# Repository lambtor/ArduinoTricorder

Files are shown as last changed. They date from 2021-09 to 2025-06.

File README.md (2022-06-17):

# ArduinoTricorder
WIP: list of digital assets that could be used with arduino tricorder 

<ul>
<li><strong>Home Screen: </strong>          showing a very simplified equivalent of windows BGInfo</li>
<li><strong>RGB Color Scanner: </strong>    OK</li>
<li><strong>Climate Scanner:</strong>		   OK - updates bar graphs to reflect data without requiring internal loops</li>
<li><strong>Left-side LED: </strong>        OK, stacks on color scanner mode</li>
<li><strong>Power LED:</strong>             Functional, will either cycle colors or show color based on battery power %</li>
<li><strong>Button Support:</strong>        OK - using easybutton library pulled from elsewhere on github (see bottom of this readme)</li>
<li><strong>Microphone Spectrum <br/>
Visualization:</strong>         OK - not the most accurate thing, but has a very high refresh rate.  Uses AdafruitZero_FFT library for FFT calculations.</li>
<li><strong>Thermal camera:</strong>       OK</li>
<li><strong>Sound playback <br/>
via trigger on <br/>
separate board:</strong>       OK</li>
<li><strong>Magnetometer for <br/>
door close to sleep:</strong>  OK</li>
<li><strong>ID LED (8) color <br/>
change via <br/>
potentiometer:</strong>  OK</li> 
	<li><strong>Neopixels above buttons:</strong>	OK - set #define NEOPIXEL_LED_COUNT 3 if you only have PWR / EMRG / ID wired up </li>
	<li><strong>Tom Servo Mode:</strong> 	OK - repeating "canned" animation</li>
  </ul>
<br/>
Draw operations on the display from the arduino typically aren't that fast.  The FFT draw code calculates a list of bar heights, then uses fillRect() to create the bars.  At the end of the bar drawing operations, these bar heights are stored in a "previous" bar height array.  From that point on, each bar draw operation calculates the difference between "new" bar heights and "previous".  If "new" is larger than "previous", it only draws enough to extend the "previous" height to the "new" one.  If "new" is less than "previous", it draws black lines to shorten the "previous" height down to the "new" one.  This relative display update method removes the use of a full screen blank operation, and minimizes flickering.<br/>
<br/>
<br/>
All 3d models for shell are available on <a href="https://www.printables.com/model/128500-star-trek-next-generation-tricorder-tr-580-v1-ardu">printables</a> or <a href="https://www.thingiverse.com/thing:5199642">thingiverse</a>. Printables has latest version with USB-C breakout plug at top of body "hat".
<br/>
Refrences used:<br/>
<a href="https://github.com/adafruit/Adafruit_nRF52_Arduino/blob/master/variants/feather_nrf52840_sense/variant.h">Adafruit board pinout map</a><br/>
<a href="https://github.com/evert-arias/EasyButton">Easybutton arduino library</a><br/><br/>

decibel demo gif

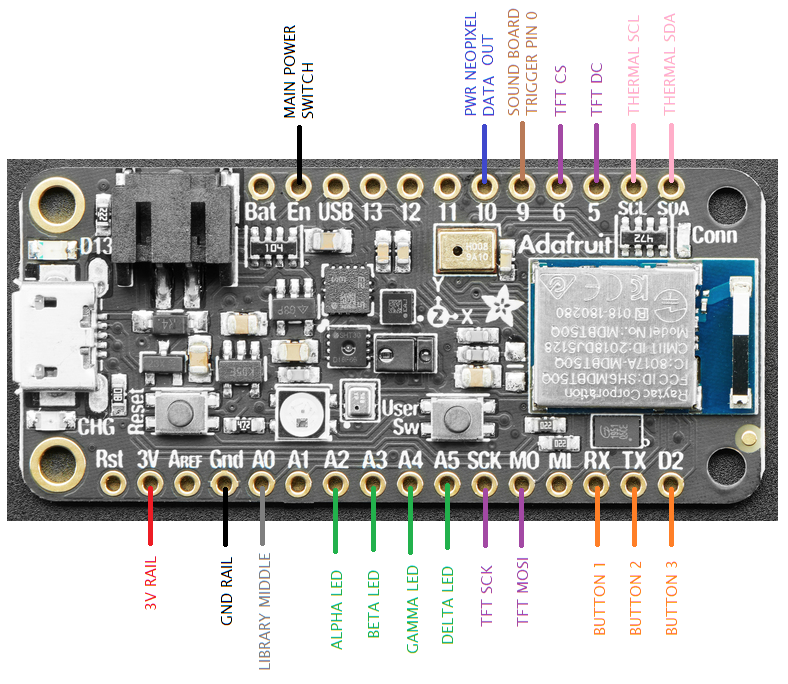
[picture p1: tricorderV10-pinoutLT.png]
board pinout


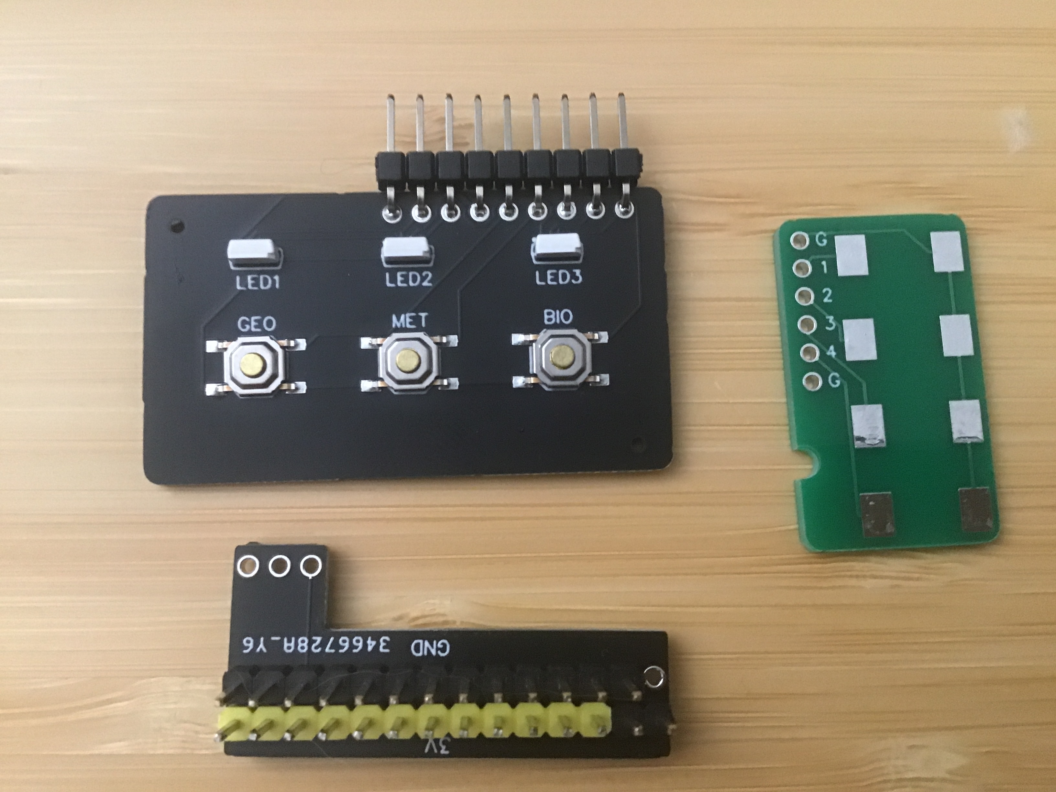
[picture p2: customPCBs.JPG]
PCB Headers


Reference of all parts used in build demoed on youtube:<br/>

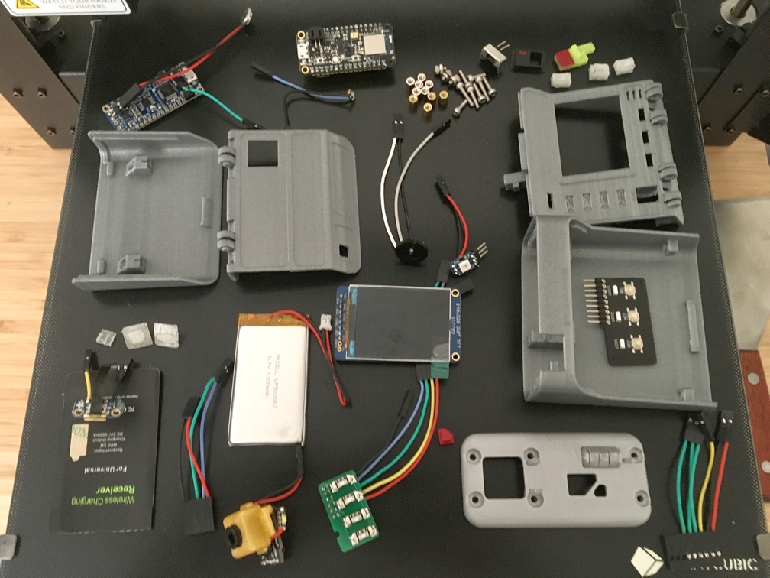
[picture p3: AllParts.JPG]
all_parts


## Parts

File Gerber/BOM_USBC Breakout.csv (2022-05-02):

ID | Name | Designator | Footprint | Quantity | Manufacturer Part | Manufacturer | Supplier | Supplier Part | Price
1 | USB-C-SMD_A4Q1605-A-03-R | U3 | USB-C-SMD_A4Q1605-A-03-R | 1 | A4Q1605-A-03-R | TECONN | LCSC | C694913 | 0.342

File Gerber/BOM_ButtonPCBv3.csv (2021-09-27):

ID | Name | Designator | Footprint | Quantity | Manufacturer Part | Manufacturer | Supplier | Supplier Part | Price
1 | LED-SMD_WS2812B-4020 | LED1,LED2,LED3 | LED-SMD_WS2812B-4020 | 3 | WS2812B-4020 | Worldsemi | LCSC | C965557 | 0.116
2 | SW-SMD_4P-L5.1-W5.1-P3.70-LS6.5-TL-2 | BIO,MET,GEO | SW-SMD_4P-L5.1-W5.1-P3.70-LS6.5-TL-2 | 3 | TS-1187A-C-C-B | XKB Enterprise | LCSC | C318889 | 0.024

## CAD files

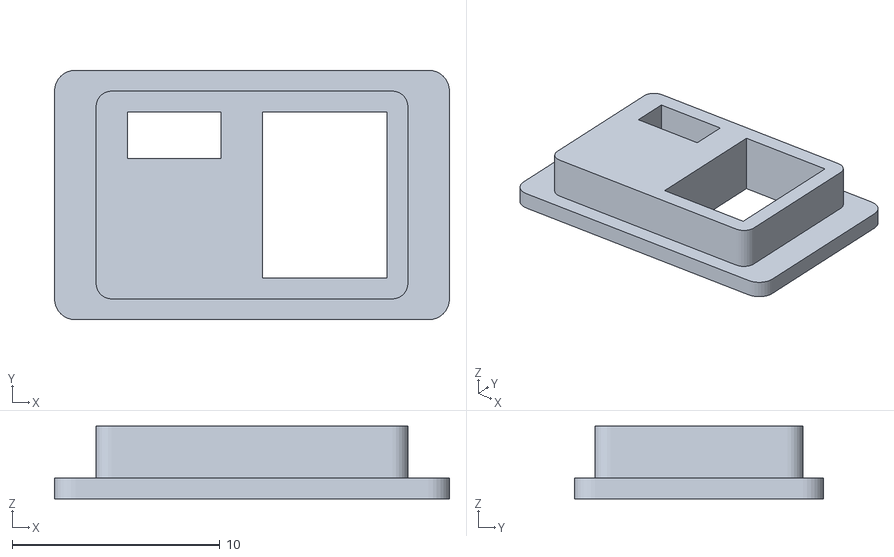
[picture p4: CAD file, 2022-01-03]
ShellModels/pwrSwitch-frame.stl
19.0 x 12.0 x 3.50

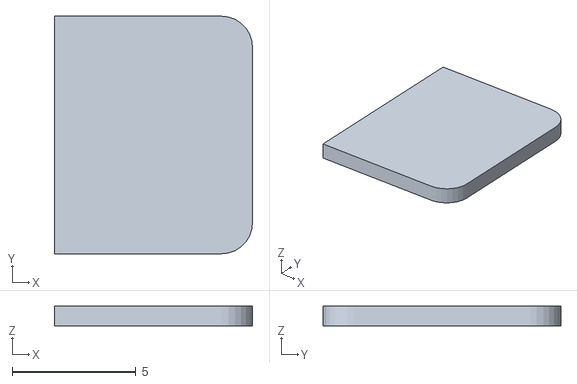
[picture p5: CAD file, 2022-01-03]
ShellModels/pwrSwitch-redSwatch.stl
8.00 x 9.60 x 0.8

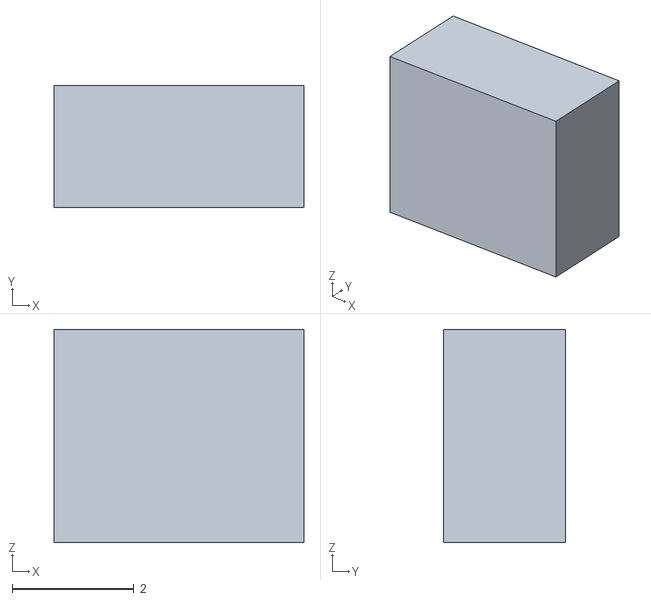
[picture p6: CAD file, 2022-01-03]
ShellModels/pwrSwitch-glass.stl
4.10 x 2.00 x 3.50

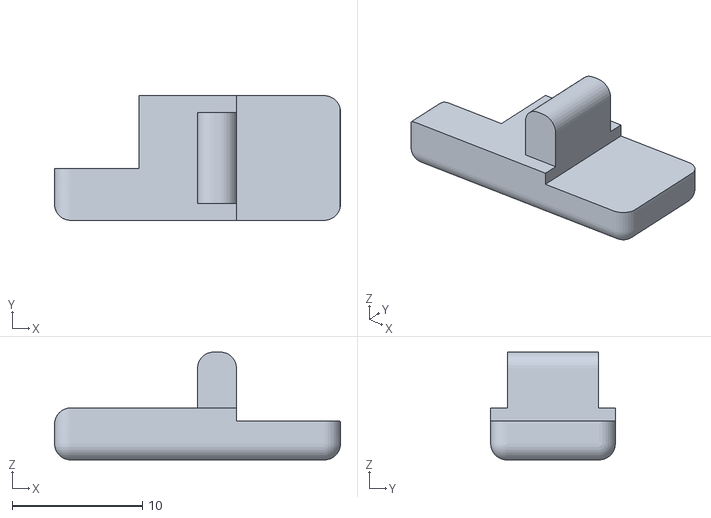
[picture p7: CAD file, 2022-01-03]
ShellModels/pwrSwitch.stl
22.0 x 9.60 x 8.30

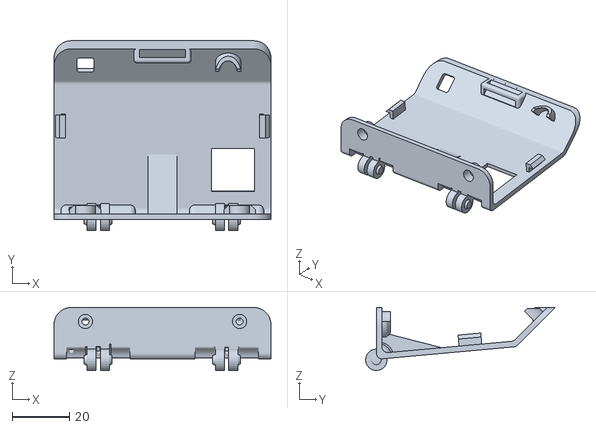
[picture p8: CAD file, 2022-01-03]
ShellModels/door-shellTop.stl
76.0 x 66.4 x 22.1

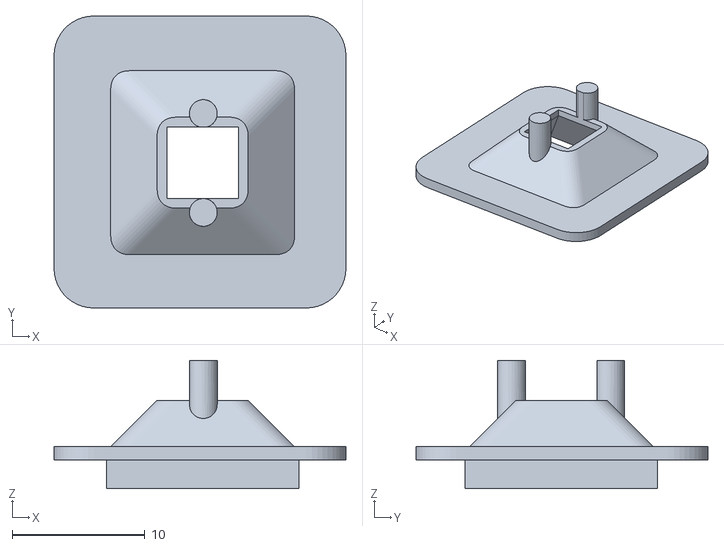
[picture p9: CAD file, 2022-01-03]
ShellModels/door-EMRGframe.stl
22.0 x 22.0 x 9.65

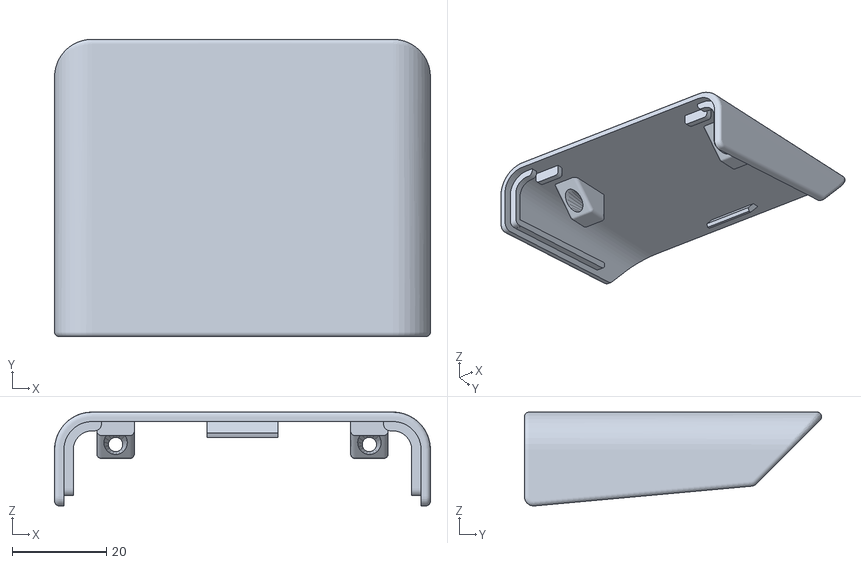
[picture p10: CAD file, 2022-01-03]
ShellModels/door-shell.stl
80.0 x 63.3 x 20.0

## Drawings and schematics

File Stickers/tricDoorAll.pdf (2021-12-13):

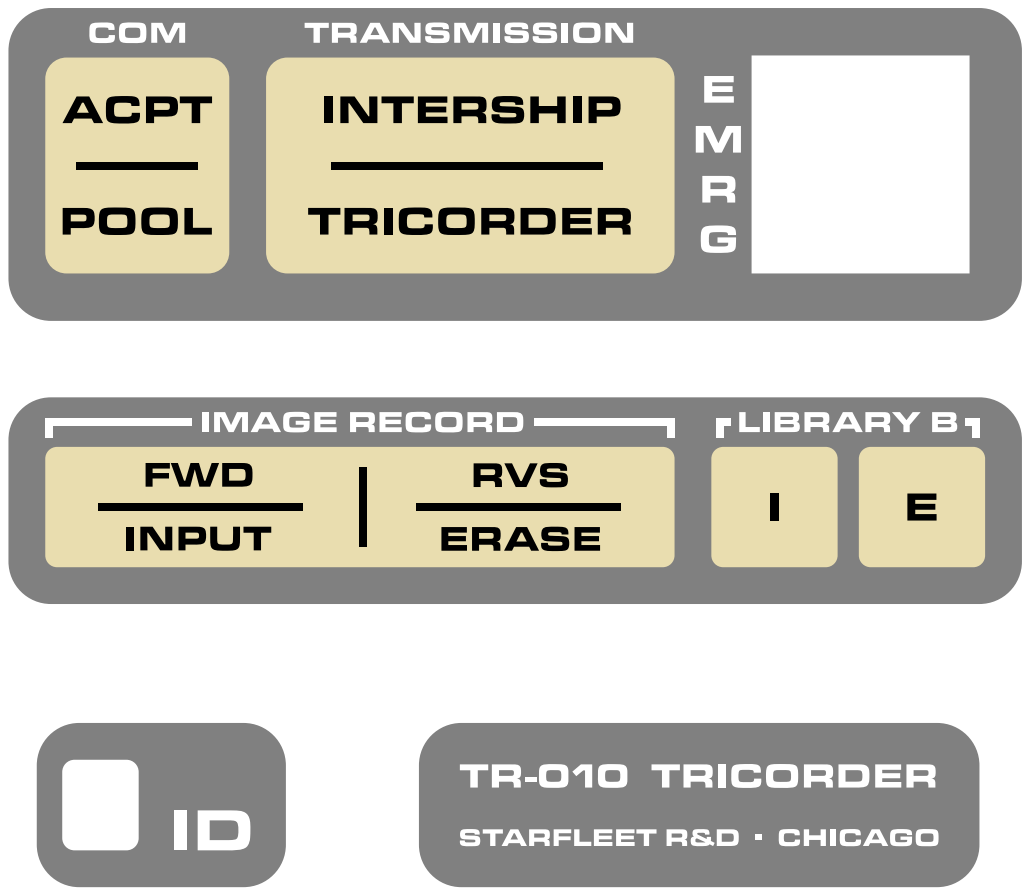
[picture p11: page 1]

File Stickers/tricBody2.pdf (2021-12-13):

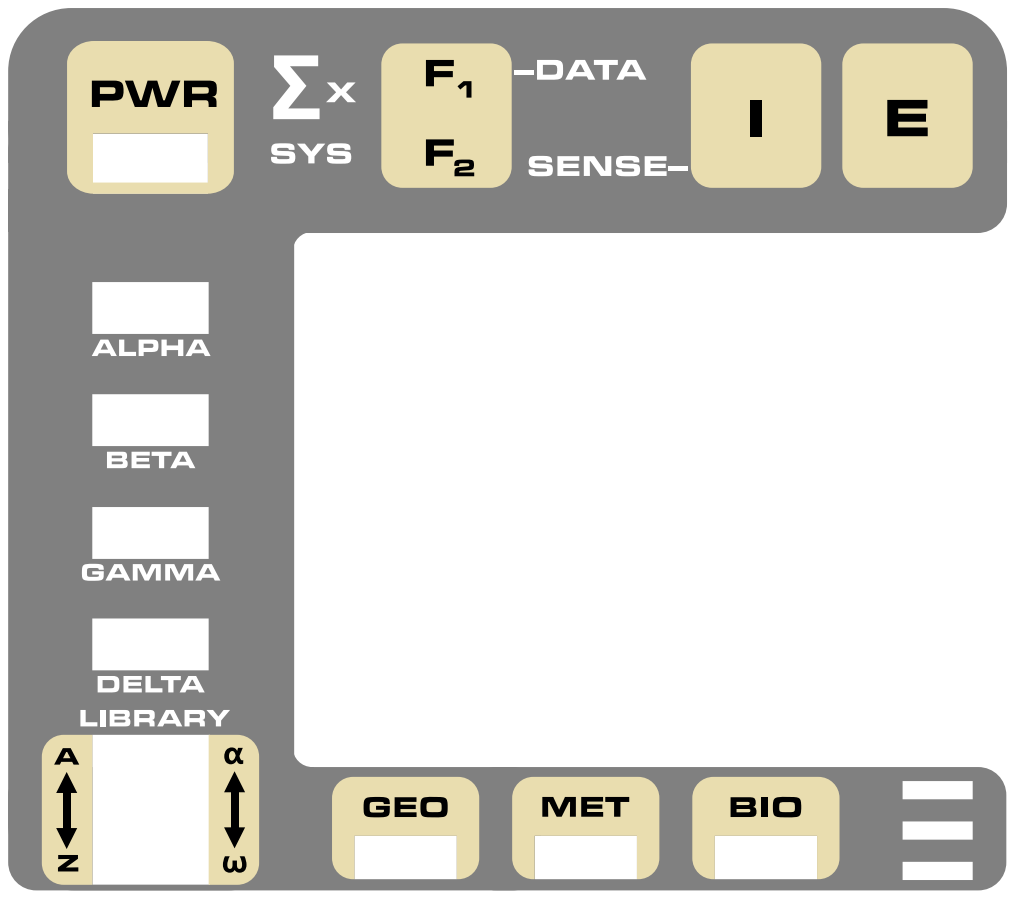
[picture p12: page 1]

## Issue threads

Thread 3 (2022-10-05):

Missing STL files

GrimWreeper, 2022-10-05:
Hi lambtor,
Firstly, great job on the build, you should be very proud.

Just wonderining if you have more STL files laying around that might have been missed in the commit? As it stands you can only print about 1/3 of a tricorder.

Best of luck to ya

GrimWreeper, 2022-10-05:
https://www.printables.com/model/128500-star-trek-next-generation-tricorder-tr-580-v1-ardu/files

found them. Ignore more. I need to RTFM.

Closed 2022-10-05.

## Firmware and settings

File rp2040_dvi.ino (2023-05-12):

// Basic full-color PicoDVI test. Provides a 16-bit color video framebuffer to
// which Adafruit_GFX calls can be made. It's based on the EYESPI_Test.ino sketch.
#include <PicoDVI.h>                  // Core display & graphics library
#include <Fonts/FreeSansBold18pt7b.h> // A custom font
#include <Fonts/lcars15pt7b.h>
#include <Fonts/lcars11pt7b.h>
#include <EasyButton.h>
#include <Adafruit_NeoPixel.h>

// Here's how a 320x240 16-bit color framebuffer is declared. Double-buffering
// is not an option in 16-bit color mode, just not enough RAM; all drawing
// operations are shown as they occur. Second argument is a hardware
// configuration -- examples are written for Adafruit Feather RP2040 DVI, but
// that's easily switched out for boards like the Pimoroni Pico DV (use
// 'pimoroni_demo_hdmi_cfg') or Pico DVI Sock ('pico_sock_cfg').
DVIGFX16 tft(DVI_RES_320x240p60, adafruit_feather_dvi_cfg);

//pin 9 is free, as pin_a6 is for vbat and is otherwise known as digital 20
#define VOLT_PIN 					D7		//INPUT_POWER_PIN
#define SOUND_TRIGGER_PIN			D9

//buttons, scroller	- d2 pin supposed to be pin #2
//button on the board is connected to pin 7.  TX is pin 0, RX is pin 1 - these are normally used for serial communication

#define BUTTON_1_PIN				PIN_SERIAL1_RX
#define BUTTON_2_PIN				PIN_SERIAL1_TX
//adafruit defines physically labeled pin D2 as pin 2 in its header file, but it does not respond when set as an input by default.
//you will need to modify system_nrf52840.c file by adding
//#define CONFIG_NFCT_PINS_AS_GPIOS (1)
//YOU WILL SEE THIS CONSTANT REFERENCED IN THAT FILE, with compiler-conditional logic around it to actually free up the NFC pins, but only if that constant exists in that file
#define BUTTON_3_PIN				D12

//pin 7 is the board button
#define BUTTON_BOARD				PIN_BUTTON
//only need 1 pin for potentiometer / scroller input. both poles need to be wired to GND and 3v - order doesn't matter
#define PIN_SCROLL_INPUT			D25

#define SCAN_LED_PIN_1 			A0
#define SCAN_LED_PIN_2 			A1
#define SCAN_LED_PIN_3 			A2
#define SCAN_LED_PIN_4 			A3
#define LED_RED             PIN_LED
#define SCAN_LED_BRIGHTNESS 	(32)

//neopixel power LED. must use an unreserved pin for this.  PWR, ID, EMRG all use this pin
#define NEOPIXEL_CHAIN_DATAPIN		(10)
#define NEOPIXEL_BRIGHTNESS 		(64)
#define NEOPIXEL_LED_COUNT 			(6)
// built-in pins: D4 = blue conn LED, 8 = neopixel on board, D13 = red LED next to micro usb port
// commented out lines are pre-defined by the adafruit board firmware
#define NEOPIXEL_BOARD_LED_PIN		(8)
//system os version #. max 3 digits
#define DEVICE_VERSION			"0.94"
//theme definition: 0 = TNG, 1 = DS9, 2 = VOY
#define UX_THEME	(0)
#define ST77XX_BLACK 0x0000
#define ST77XX_RED 0xF800
#define ST77XX_WHITE 0xFFFF

#if UX_THEME == 0
	// TNG colors here
	#define color_SWOOP				0xF7B3
	#define color_MAINTEXT			0x9E7F
	//#define color_MAINTEXT			0xC69F
	#define color_LABELTEXT			0x841E
	#define color_HEADER			0xFEC8
	#define color_TITLETEXT			0xFEC8
	//196,187,145
	#define color_LABELTEXT2		0xC5D2
	//204,174,220
	#define color_LABELTEXT3		0xCD7B
	#define color_LABELTEXT4		0xEE31
	#define color_LEGEND			0x6A62
	//210,202,157
	#define color_FFT				0xDEB5
#elif UX_THEME == 1
	// ds9
	#define color_SWOOP			0xD4F0
	#define color_MAINTEXT		0xBD19
	#define color_LABELTEXT		0x7A8D
	#define color_HEADER		0xECA7
	#define color_TITLETEXT		0xC3ED
	//to-do: find fitting options for these to mesh with ds9
	#define color_LABELTEXT2	0xC5D2	
	#define color_LABELTEXT3		0xCD7B	
	#define color_LABELTEXT4		0xEE31
	#define color_LEGEND			0x6A62
	#define color_FFT				0xDEB5
#elif UX_THEME == 2
	// voy
	#define color_MAINTEXT		0x9E7F
	#define color_SWOOP			0x7C34
	#define color_LABELTEXT		0x9CDF
	#define color_HEADER		0xCB33
	#define color_TITLETEXT		0xFFAF
	//to-do: find fitting options for these to mesh with voy
	#define color_LABELTEXT2	0xC5D2
	#define color_LABELTEXT3		0xCD7B
	#define color_LABELTEXT4		0xEE31
	#define color_LEGEND			0x6A62
	#define color_FFT				0xDEB5
#endif

#define color_REDLABELTEXT		0xE000
#define color_REDDARKLABELTEXT	0x9800
#define color_REDDATATEXT		0xDEFB

//use labeltext3 for servo ltpurple
#define color_SERVOPINK			0xFE18
#define color_SERVOPURPLE		0x83B7
#define RGBto565(r,g,b) ((((r) & 0xF8) << 8) | (((g) & 0xFC) << 3) | ((b) >> 3))
Adafruit_NeoPixel ledBoard(1, NEOPIXEL_BOARD_LED_PIN, NEO_GRB + NEO_KHZ800);

//power & board color enumerator: blue = 4, green = 3, yellow = 2, orange = 1, red = 0
int mnPowerColor = 4;
bool mbCyclePowerColor = false;
bool mbCycleBoardColor = false;
int mnBoardColor = 4;
//power interval doesn't need to check more than every 30 seconds
int mnPowerLEDInterval = 30000;
int mnIDLEDInterval = 1000;
unsigned long mnLastUpdateIDLED = 0;
int mnCurrentProfileRed = 0;
int mnCurrentProfileGreen = 0;
int mnCurrentProfileBlue = 0;
String msCurrentProfileName = "";
int mnEMRGLEDInterval = 110;
int mnEMRGMinStrength = 8;
int mnEMRGMaxStrength = 212;
int mnEMRGCurrentStrength = 8;
bool mbLEDIDSet = false;
unsigned long mnLastUpdatePower = 0;
unsigned long mnLastUpdateEMRG = 0;
bool mbEMRGdirection = false;
int mnBoardLEDInterval = 5000;
unsigned long mnLastUpdateBoard = 0;

//left scanner leds
int mnLeftLEDInterval = 200;
int mnLeftLEDCurrent = 0;
unsigned long mnLastUpdateLeftLED = 0;

int mnBoardRedLEDInterval = 350;
int mnBoardBlueLEDInterval = 250;
unsigned long mnLastUpdateBoardRedLED = 0;
unsigned long mnLastUpdateBoardBlueLED = 0;
bool mbBoardRedLED = false;
bool mbBoardBlueLED = false;
//button functionality
bool mbButton1Flag = false;
bool mbButton2Flag = false;
bool mbButton3Flag = false;
bool mbButton7Flag = false;
EasyButton oButton1(BUTTON_1_PIN);
EasyButton oButton2(BUTTON_2_PIN);
EasyButton oButton3(BUTTON_3_PIN);
//board button digital pin 7 - use for thermal camera toggle
EasyButton oButton7(BUTTON_BOARD);

bool mbSleepMode = false;
bool mbTomServoActive = false;
unsigned long mnButton2Press = 0;
unsigned long mnButton3Press = 0;
int mnServoButtonWindow = 1500;
//graphs should take 3 seconds for full draw cycle-> 3000 / 80 lines
uint8_t mnServoDrawInterval = 38;
unsigned long mnServoLastDraw = 0;
uint8_t mnCurrentServoGraphPoint = 0;

bool mbHomeActive = false;
unsigned long mnLastUpdateHome = 0;
int mnHomeUpdateInterval = 1000;
bool mbColorInitialized = false;
bool mbRGBActive = false;
int mnRGBScanInterval = 5000;
int mnRGBCooldown = 0;
unsigned long mnLastRGBScan = 0;
bool mbTempInitialized = false;
bool mbHumidityInitialized = false;
bool mbTempActive = false;
bool mbThermalCameraStarted = false;
bool mbThermalActive = false;
bool mbHumidBarComplete = false;
bool mbTempBarComplete = false;
bool mbBaromBarComplete = false;
bool mbMicrophoneStarted = false;
bool mbMicrophoneActive = false;
bool mbMicrophoneRedraw = false;
int mnClimateCooldown = 0;
int mnTempTargetBar = 0;
int mnTempCurrentBar = 0;
int mnHumidTargetBar = 0;
int mnHumidCurrentBar = 0;
int mnBaromTargetBar = 0;
int mnBaromCurrentBar = 0;

//establish graph values
const uint8_t mnarrServoGraphData[] = {3,7,10,12,13,14,14,14,13,12,10,7,4,4,6,8,11,13,14,15,15,15,15,14,13,
									12,10,8,7,6,4,3,2,2,2,3,4,6,8,9,11,12,12,12,11,10,9,7,5,3,3,3,5,7,10,
									11,11,12,12,12,11,11,10,9,9,9,8,8,8,8,7,6,5,5,5,5,4,3,2,2,2};
									

void setup() {
	//NRF_UICR->NFCPINS = 0;
	ledBoard.begin();
	
	//dvi uses begin as initialization
	tft.begin();
	//tft.setRotation(1);
	tft.setFont(&lcars11pt7b);
	tft.setTextSize(1);
	//these goggles, they do nothing!
	tft.setTextWrap(false);
		
	ledBoard.clear();
	ledBoard.setBrightness(NEOPIXEL_BRIGHTNESS);
	
	//set pinmode output for scanner leds
	pinMode(SCAN_LED_PIN_1, OUTPUT);
	pinMode(SCAN_LED_PIN_2, OUTPUT);
	pinMode(SCAN_LED_PIN_3, OUTPUT);
	pinMode(SCAN_LED_PIN_4, OUTPUT);
	
	//set output for board non-neopixel LEDs
	pinMode(LED_RED, OUTPUT);
	
	pinMode(SOUND_TRIGGER_PIN, OUTPUT);
	digitalWrite(SOUND_TRIGGER_PIN, HIGH);
		
	//or it'll be read as low and boot the tricorder into environment section
	pinMode(BUTTON_1_PIN, OUTPUT);
	pinMode(BUTTON_2_PIN, OUTPUT);
	pinMode(BUTTON_3_PIN, OUTPUT);
	pinMode(BUTTON_BOARD, OUTPUT);
	digitalWrite(BUTTON_1_PIN, HIGH);
	digitalWrite(BUTTON_2_PIN, HIGH);
	digitalWrite(BUTTON_3_PIN, HIGH);
	digitalWrite(BUTTON_BOARD, HIGH);	
	delay(10);
		
	//pinMode(PIN_SCROLL_INPUT, INPUT);
	
	pinMode(BUTTON_1_PIN, INPUT);
	pinMode(BUTTON_2_PIN, INPUT);
	pinMode(BUTTON_3_PIN, INPUT);
	
	//pinMode(VOLT_PIN, INPUT);	
	pinMode(BUTTON_BOARD, INPUT);	
	
	/*oButton2.begin();
	oButton2.onPressed(ToggleRGBSensor);	
	
	oButton1.begin();
	oButton1.onPressed(ToggleClimateSensor);
	
	oButton3.begin();
	oButton3.onPressed(ToggleMicrophone);*/
	
	oButton7.begin();
	oButton7.onPressed(ToggleTomServo);
	
	GoHome();
}

void loop() {
	//toggle climate
	oButton1.read();
	//this toggles RGB scanner
	oButton2.read();	
	//toggle microphone
	oButton3.read();
	//toggle thermal camera
	oButton7.read();
			
	RunNeoPixelColor(NEOPIXEL_BOARD_LED_PIN);
	//RunLeftScanner();
	RunHome();
	//blink board LEDs
	RunBoardLEDs();	
	RunTomServo();
}

void GoHome() {
	//if flag set for thermal debug mode, hijack home screen?	
	//reset any previous sensor statuses
	mnRGBCooldown = 0;
	mnClimateCooldown = 0;
	mbHomeActive = true;
	mbRGBActive = false;
	mbTempActive = false;
	mnCurrentServoGraphPoint = 0;
	mnServoLastDraw = 0;
	//SetActiveNeoPixelButton(0);
	
	mbButton1Flag = false;
	mbButton2Flag = false;
	mbButton3Flag = false;
	
	//reset any bar graph values from climate
	mnTempTargetBar = 0;
	mnTempCurrentBar = 0;
	mnHumidTargetBar = 0;
	mnHumidCurrentBar = 0;
	mnBaromTargetBar = 0;
	mnBaromCurrentBar = 0;
	mbHumidBarComplete = false;
	mbTempBarComplete = false;
	mbBaromBarComplete = false;
	mbThermalActive = false;
	mbTomServoActive = false;

	//tft.setFont(&lcars11pt7b);
	tft.setFont(&lcars15pt7b);

	// large block of text
	tft.fillScreen(ST77XX_BLACK);
	// home screen header is 2 rounded rectangles, lines to cut them, 1 black rect as backing for header text
	//fillRoundRect(x,y,width,height,cornerRadius, color)
	//top and bottom borders
	tft.fillRoundRect(26, 1, 289, 22, 11, color_SWOOP);
	tft.fillRoundRect(26, 216, 289, 22, 11, color_SWOOP);
	//left side
	tft.fillRoundRect(1, 1, 68, 66, 32, color_SWOOP);
	tft.fillRoundRect(1, 171, 68, 66, 32, color_SWOOP);
	tft.fillRoundRect(59, 23, 24, 193, 11, ST77XX_BLACK);
	//middle section - needs to be split for profile name and color
	//tft.fillRect(1, 39, 58, 164, color_HEADER);
	//dull all LED colors by 50% to lcarsify them
	tft.fillRect(1, 39, 58, 76, RGBto565((int)min(mnCurrentProfileRed*1.75, 255), (int)min(mnCurrentProfileGreen*1.75, 255), (int)min(mnCurrentProfileBlue*1.75, 255)));
	tft.fillRect(1, 147, 58, 55, RGBto565((int)min(mnCurrentProfileRed*1.75, 255), (int)min(mnCurrentProfileGreen*1.75, 255), (int)min(mnCurrentProfileBlue*1.75, 255)));
	//profile label always shows bkg as swoop color 
	tft.fillRect(1, 119, 58, 24, color_SWOOP);
	
	//middle section black lines
	tft.drawFastHLine(1, 35, 58, ST77XX_BLACK);
	tft.drawFastHLine(1, 36, 58, ST77XX_BLACK);
	tft.drawFastHLine(1, 37, 58, ST77XX_BLACK);
	tft.drawFastHLine(1, 38, 58, ST77XX_BLACK);
	tft.drawFastHLine(1, 39, 58, ST77XX_BLACK);	
	tft.drawFastHLine(1, 40, 58, ST77XX_BLACK);	
	tft.drawFastHLine(1, 201, 58, ST77XX_BLACK);
	tft.drawFastHLine(1, 202, 58, ST77XX_BLACK);
	tft.drawFastHLine(1, 203, 58, ST77XX_BLACK);
	tft.drawFastHLine(1, 204, 58, ST77XX_BLACK);
	tft.drawFastHLine(1, 205, 58, ST77XX_BLACK);
	tft.drawFastHLine(1, 206, 58, ST77XX_BLACK);
	//bottom right
	tft.drawFastVLine(296, 216, 22, ST77XX_BLACK);
	tft.drawFastVLine(297, 216, 22, ST77XX_BLACK);	
	tft.drawFastVLine(298, 216, 22, ST77XX_BLACK);
	tft.drawFastVLine(299, 216, 22, ST77XX_BLACK);
	tft.drawFastVLine(300, 216, 22, ST77XX_BLACK);
	tft.drawFastVLine(301, 216, 22, ST77XX_BLACK);	

	//black section for home screen title
	tft.fillRect(232, 1, 69, 22, ST77XX_BLACK);
	drawParamText(229, 21, "  STATUS", color_MAINTEXT);
	//drawParamText(229, 21, "  ABOUT", color_MAINTEXT);
	
	tft.fillRoundRect(76, 39, 14, 11, 5, color_LABELTEXT);
	tft.fillRoundRect(76, 63, 14, 11, 5, color_LABELTEXT);
	tft.fillRoundRect(76, 87, 14, 11, 5, color_LABELTEXT);
	
	tft.fillRoundRect(162, 39, 14, 11, 5, color_MAINTEXT);
	tft.fillRoundRect(162, 63, 14, 11, 5, color_MAINTEXT);
	tft.fillRoundRect(162, 87, 14, 11, 5, color_MAINTEXT);

	tft.fillRoundRect(252, 87, 14, 11, 5, color_MAINTEXT);
	//set font to 11pt since header is done	
	tft.setFont(&lcars11pt7b);
	
	drawParamText(6, 138, msCurrentProfileName, ST77XX_BLACK);
	
	drawParamText(101, 50, "POWER", color_LABELTEXT);
	drawParamText(101, 75, "UPTIME", color_LABELTEXT);
	drawParamText(101, 100, "CPU", color_LABELTEXT);
	
	//number only for battery level
	ShowBatteryLevel(213, 50, color_LABELTEXT, color_MAINTEXT);
	//uptime
	drawParamText(185, 75, "00:00.00", color_MAINTEXT);
	//cpu speed - hz to mhz conversion is to divide by 1 million exactly
	drawParamText(204, 100, String((float) F_CPU / 1000000.0), color_MAINTEXT);
	//device version
	drawParamText(235, 100, "           " + String(DEVICE_VERSION), color_MAINTEXT);
		
	tft.fillRect(70, 119, 81, 34, color_LABELTEXT2);	
  
	//drawParamText(159, 138, "CLIMATE", ST77XX_BLACK);
	drawParamText(78, 142, "CLIMATE", ST77XX_BLACK);
				
	tft.fillRect(70, 168, 82, 34, color_LABELTEXT2);
	drawParamText(78, 191, "CHROMATICS", ST77XX_BLACK);
	//drawParamText(137, 169, "CHROMATICS", ST77XX_BLACK);
	
	tft.fillRect(192, 119, 82, 34, color_LABELTEXT2);
	//drawParamText(169, 200, "SONICS", ST77XX_BLACK);
	drawParamText(200, 142, "SONICS", ST77XX_BLACK);
		
	tft.fillRect(192, 168, 82, 34, color_LABELTEXT2);
	drawParamText(200, 191, "THERMAL", ST77XX_BLACK);
		
	//black lines to separate rectangles from caps
	tft.drawFastVLine(152, 119, 84, ST77XX_BLACK);
	tft.drawFastVLine(153, 119, 84, ST77XX_BLACK);
	tft.drawFastVLine(154, 119, 84, ST77XX_BLACK);
	tft.drawFastVLine(155, 119, 84, ST77XX_BLACK);
	tft.drawFastVLine(156, 119, 84, ST77XX_BLACK);
	tft.drawFastVLine(157, 119, 84, ST77XX_BLACK);
	tft.drawFastVLine(158, 119, 84, ST77XX_BLACK);
	tft.drawFastVLine(275, 119, 84, ST77XX_BLACK);
	tft.drawFastVLine(276, 119, 84, ST77XX_BLACK);
	tft.drawFastVLine(277, 119, 84, ST77XX_BLACK);
	tft.drawFastVLine(278, 119, 84, ST77XX_BLACK);
	tft.drawFastVLine(279, 119, 84, ST77XX_BLACK);
	tft.drawFastVLine(280, 119, 84, ST77XX_BLACK);
	tft.drawFastVLine(281, 119, 84, ST77XX_BLACK);			
}

void drawParamCharText(uint8_t nPosX, uint8_t nPosY, char *sText, uint16_t nColor) {
	tft.setCursor(nPosX, nPosY);
	tft.setTextColor(nColor);
	tft.setTextWrap(true);
	tft.print(sText);
}

void drawParamText(uint8_t nPosX, uint8_t nPosY, String sText, uint16_t nColor) {
	tft.setCursor(nPosX, nPosY);
	tft.setTextColor(nColor);
	tft.setTextWrap(true);
	tft.print(sText);
}

int GetBuffer(double dInput) {
	if (dInput < 10) {
		return 14;
	} else if (dInput < 100) {
		return 8;
	} 
	return 0;
}

int GetBuffer(int nInput) {
	if (nInput < 10) {
		return 14;
	} else if (nInput < 100) {
		return 8;
	} else {
		return 0;
	}
}

void RunNeoPixelColor(int nPin) {
	unsigned long lTimer = millis();
	if (nPin == NEOPIXEL_BOARD_LED_PIN) {
		//unsure if want to use, as this needs to be sensor flash.
		//this has a separate update interval from power because we want this to come back faster than 30 seconds after color scanner is used
		if (!mbRGBActive) {
			if ((lTimer - mnLastUpdateBoard) > mnBoardLEDInterval) {
				if (mbCycleBoardColor == false) {
					int nBattMapBoard = GetBatteryTier();
					//cycle order = blue, green, yellow, orange, red
					switch (nBattMapBoard) {
						case 5: ledBoard.setPixelColor(0, 0, 0, 128); break;
						case 4: ledBoard.setPixelColor(0, 0, 0, 128); break;
						case 3: ledBoard.setPixelColor(0, 0, 128, 0); break;
						case 2: ledBoard.setPixelColor(0, 112, 128, 0); break;
						case 1: ledBoard.setPixelColor(0, 128, 96, 0); break;
						default: ledBoard.setPixelColor(0, 128, 0, 0); break;
					}							
				} else {
					switch (mnBoardColor) {
						case 4: ledBoard.setPixelColor(0, 0, 0, 128); mnBoardColor = 3; break;
						case 3: ledBoard.setPixelColor(0, 0, 128, 0); mnBoardColor = 2; break;
						case 2: ledBoard.setPixelColor(0, 112, 128, 0); mnBoardColor = 1; break;
						case 1: ledBoard.setPixelColor(0, 128, 96, 0); mnBoardColor = 0; break;
						default: ledBoard.setPixelColor(0, 128, 0, 0); mnBoardColor = 4; break;
					}
				}
				mnLastUpdateBoard = lTimer;
				ledBoard.show();
			}
		} else {
			//color scanner app running - do nothing
		}
	}
}


void RunHome() {	
	if (!mbHomeActive) return;
	
	unsigned long nNowMillis = millis();
	
	//show system uptime, battery level		
	if (nNowMillis - mnLastUpdateHome > mnHomeUpdateInterval) {
		//blank last uptime display, refresh values
		int nUptimeSeconds = (nNowMillis / 1000);
		int nUptimeMinutes = (nUptimeSeconds / 60);
		int nDisplayMinutes = nUptimeMinutes;
		int nUptimeHours = nUptimeMinutes / 60;
		int nDisplaySeconds = nUptimeSeconds;
		
		//only update battery level every 5 seconds
		if ((nUptimeSeconds % 10) == 0) {
			tft.fillRect(205, 35, 30, 24, ST77XX_BLACK);
			ShowBatteryLevel(213, 50, color_LABELTEXT, color_MAINTEXT);
		}
		
		if (nUptimeHours > 0) {
			nDisplayMinutes = nUptimeMinutes - (nUptimeHours * 60);			
		}
		if (nUptimeMinutes > 0) {
			nDisplaySeconds = nUptimeSeconds - (nUptimeMinutes * 60);
		}
		
		String sUptime = (nUptimeHours > 9 ? String(nUptimeHours) : "0" + String(nUptimeHours) ) + ":" + (nDisplayMinutes > 9 ? String(nDisplayMinutes) : "0" + String(nDisplayMinutes)) + "." + (nDisplaySeconds > 9 ? String(nDisplaySeconds) : "0" + String(nDisplaySeconds));
		tft.fillRect(180, 58, 58, 25, ST77XX_BLACK);
		drawParamText(185, 75, sUptime, color_MAINTEXT);
		
		//show profile color and name in left frame border
		//tft.fillRect(1, 39, 58, 76, RGBto565((int)(mnCurrentProfileRed), (int)(mnCurrentProfileGreen), (int)(mnCurrentProfileBlue)));
		//tft.fillRect(1, 147, 58, 55, RGBto565((int)(mnCurrentProfileRed), (int)(mnCurrentProfileGreen), (int)(mnCurrentProfileBlue)));
		tft.fillRect(1, 39, 58, 76, RGBto565((int)min(mnCurrentProfileRed*1.75, 255), (int)min(mnCurrentProfileGreen*1.75, 255), (int)min(mnCurrentProfileBlue*1.75, 255)));
		tft.fillRect(1, 147, 58, 55, RGBto565((int)min(mnCurrentProfileRed*1.75, 255), (int)min(mnCurrentProfileGreen*1.75, 255), (int)min(mnCurrentProfileBlue*1.75, 255)));
		//profile label always shows bkg as swoop color
		tft.fillRect(1, 119, 58, 24, color_SWOOP);
		drawParamText(6, 138, msCurrentProfileName, ST77XX_BLACK);
				
		mnLastUpdateHome = nNowMillis;
	}
	
}

void ShowBatteryLevel(int nPosX, int nPosY, uint16_t nLabelColor, uint16_t nValueColor) {
	String sBatteryStatus = "";  
	int nBattPct = GetBatteryPercent();
	//need to use space characters to pad string because it'll wrap back around to left edge when cursor starting point set over 240.
	//this is a glitch of adafruit GFX library - it thinks display is 240x320 despite the rotation in setup() and setting for text wrap
	//sBatteryStatus = "      " + String((int)fBattV);
	sBatteryStatus = String(nBattPct);
	drawParamText(nPosX + GetBuffer(nBattPct), nPosY, sBatteryStatus, color_MAINTEXT);	
	//float sRawVolt = (analogRead(VOLT_PIN) * 7.2) / 1024;
	//drawParamText(nPosX + GetBuffer(nBattPct), nPosY, String(sRawVolt), color_MAINTEXT);
}

uint8_t GetBatteryTier() {
	//int nBattPct = map(fBattV, 320, 420, 0, 100);
	int nBattPct = GetBatteryPercent();
	//divide by 20 converts the % to a number 0-4. we have 5 total colors for conveying battery level.
	return (nBattPct / 20);	
}

uint8_t GetBatteryPercent() {
	float fBattV = analogRead(VOLT_PIN);
	//fBattV *= 2;    // we divided by 2 (board has a resistor on this pin), so multiply back,  // Multiply by 3.3V, our reference voltage
	// apparently, previous versions used 3.3 as battery reference, but now this is 3.6
	// for this reason, if you use 3.3 with a newer version of firmware, batt % will show 60 when it should be 100
	//fBattV *= 3.6; 	
	//combine previous actions for brevity- multiply by 2 to adjust for resistor, then 3.3 reference voltage
	fBattV *= 7.2;
	fBattV /= 1024; // convert to voltage
	//3.2 to 4.2 => subtract 3.2 (0) from current voltage. now values should be in range of 0-0.9 : multiply by 1.111, then by 100, convert result to int.
	//fBattV -= 3.2;	
	//convert voltage to a percentage
	fBattV = fBattV * 100;
	fBattV = constrain(fBattV, 320, 420);
	int nBattPct = map(fBattV, 320, 420, 0, 100);
	return nBattPct;
}
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

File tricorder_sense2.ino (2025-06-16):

#include <Adafruit_NeoPixel.h>
#include <SPI.h>
#include <Adafruit_GFX.h>    	// Core graphics library
#include <Adafruit_ST7789.h> 	// Hardware-specific library for ST7789
#include <string.h>
#include <Adafruit_APDS9960.h>	//RGB, light, proximity, gesture sensor
#include <Wire.h>
#include <EasyButton.h>
#include <Adafruit_BMP280.h>	//altitude, barometer
#include <Adafruit_SHT31.h>		//temp, humidity
#include <Adafruit_Sensor.h>	//wtf is this??
#include <PDM.h>
#include <Adafruit_ZeroFFT.h>
#include <MLX90640_API.h>
#include <MLX90640_I2C_Driver.h>
#include <Adafruit_LIS3MDL.h>	//magnetometer, for door close detection
#include <Adafruit_LSM6DS33.h>

//full arduino pinout for this board is here:
/*https://github.com/adafruit/Adafruit_nRF52_Arduino/blob/master/variants/feather_nrf52840_sense/variant.h*/

// need to remove hyphens from header filenames or exception will get thrown
#include "Fonts/lcars15pt7b.h"
#include "Fonts/lcars11pt7b.h"

// For the breakout board, you can use any 2 or 3 pins.
// These pins will also work for the 1.8" TFT shield.
//need to use pin 6 for TFT_CS, as pin 20 is analog 7. analog 7 is the only way to get current voltage, which is used for battery %

//MISO is not required for screen to work - this is used by mem card only?
#define TFT_CS 						(6)
// SD card select pin
//#define SD_CS 			11 	//- can't use pin 4 as that is for blue connection led
#define SD_CS				(12)
#define TFT_BKLT						(11)
#define TFT_RST 					-1
#define TFT_DC 						(5)
#define USE_SD_CARD 				(0)

//pin 9 is free, as pin_a6 is for vbat and is otherwise known as digital 20
#define VOLT_PIN 					PIN_A6		//INPUT_POWER_PIN
#define SOUND_TRIGGER_PIN			(9)
// set this to false if sound trigger pin should hold low the entire time sound plays
// set this to true for trigger pin to get pulled low for 100ms then return to high
const bool SOUND_BUTTON_TRIGGERSTYLE = false;
bool mbSoundPlaying = false;

//buttons, scroller	- d2 pin supposed to be pin #2
//button on the board is connected to pin 7.  TX is pin 0, RX is pin 1 - these are normally used for serial communication

#define BUTTON_1_PIN				PIN_SERIAL1_RX
#define BUTTON_2_PIN				PIN_SERIAL1_TX
//adafruit defines physically labeled pin D2 as pin 2 in its header file, but it does not respond when set as an input by default.
//you will need to modify system_nrf52840.c file by adding
//#define CONFIG_NFCT_PINS_AS_GPIOS (1)
//YOU WILL SEE THIS CONSTANT REFERENCED IN THAT FILE, with compiler-conditional logic around it to actually free up the NFC pins, but only if that constant exists in that file
#define BUTTON_3_PIN				(2)

//pin 7 is the board button
#define BUTTON_BOARD				PIN_BUTTON1
//only need 1 pin for potentiometer / scroller input. both poles need to be wired to GND and 3v - order doesn't matter
#define PIN_SCROLL_INPUT			PIN_A0

#define SCAN_LED_PIN_1 			PIN_A2
#define SCAN_LED_PIN_2 			PIN_A3
#define SCAN_LED_PIN_3 			PIN_A4
#define SCAN_LED_PIN_4 			PIN_A5

#define SCAN_LED_BRIGHTNESS 	(32)

//neopixel power LED. must use an unreserved pin for this.  PWR, ID, EMRG all use this pin
#define NEOPIXEL_CHAIN_DATAPIN		(10)
#define NEOPIXEL_BRIGHTNESS 		(64)
#define NEOPIXEL_LED_COUNT 			(6)
// built-in pins: D4 = blue conn LED, 8 = neopixel on board, D13 = red LED next to micro usb port
// commented out lines are pre-defined by the adafruit board firmware
#define NEOPIXEL_BOARD_LED_PIN		(8)
//#define PIN_NEOPIXEL 				8
//#define BOARD_REDLED_PIN 			13
//#define BOARD_BLUELED_PIN 		4
//#define LED_RED 					13
//#define LED_BLUE					4

//system os version #. max 3 digits
#define DEVICE_VERSION			"0.97"
//theme definition: 0 = TNG, 1 = DS9, 2 = VOY
#define UX_THEME	(0)
#define THERMAL_CAMERA_PORTRAIT		(1)

//uncomment this line to have raw magnetometer z value displayed on home screen
//#define MAGNET_DEBUG	(0)
//the -700 threshold was based on resolution of 10, or 1024 max
//-20000 is based on the analog resolution required by battery pin (-32768 to 32768 range)
//this is intended for the z index reading of magnetometer (negative means field is below the board)
int mnMagnetSleepThreshold = -29500;

#if UX_THEME == 0
	// TNG colors here
	//241,247,153		#f7f79c
	#define color_SWOOP				0xF7B3
	//			#9cceff
	#define color_MAINTEXT			0x9E7F
	//			#c5d2ff
	//#define color_MAINTEXT			0xC69F
	//			#8482f7
	#define color_LABELTEXT			0x841E
	//	#ffdb42
	#define color_HEADER			0xFEC8
	#define color_TITLETEXT			0xFEC8
	//196,187,145		#c5ba94
	#define color_LABELTEXT2		0xC5D2
	//204,174,220		#ceaede
	#define color_LABELTEXT3		0xCD7B
	//#efc68c
	#define color_LABELTEXT4		0xEE31
	//#6b4d10
	#define color_LEGEND			0x6A62
	//210,202,157
	#define color_FFT				0xDEB5
#elif UX_THEME == 1
	// DS9
	//#d69e84
	#define color_SWOOP			0xD4F0
	//#bda2ce
	#define color_MAINTEXT		0xBD19
	//#7b516b
	#define color_LABELTEXT		0x7A8D
	//#ef963a
	#define color_HEADER		0xECA7
	//#c57d6b
	#define color_TITLETEXT		0xC3ED
	//to-do: find fitting options for these to mesh with ds9
	#define color_LABELTEXT2		0xC5D2	
	#define color_LABELTEXT3		0xCD7B	
	#define color_LABELTEXT4		0xEE31
	#define color_LEGEND			0x6A62
	#define color_FFT				0xDEB5
#elif UX_THEME == 2
	// VOY
	//#9cceff
	#define color_MAINTEXT		0x9E7F
	//#7b86a5
	#define color_SWOOP			0x7C34
	//#9c9aff
	#define color_LABELTEXT		0x9CDF
	//#ce659c
	#define color_HEADER		0xCB33
	//#fff77b
	#define color_TITLETEXT		0xFFAF
	//to-do: find fitting options for these to mesh with voy
	#define color_LABELTEXT2		0xC5D2
	#define color_LABELTEXT3		0xCD7B
	#define color_LABELTEXT4		0xEE31
	#define color_LEGEND			0x6A62
	#define color_FFT				0xDEB5
#endif

//#e60000
#define color_REDLABELTEXT		0xE000
//#9c0000
#define color_REDDARKLABELTEXT	0x9800
//#dedfde
#define color_REDDATATEXT		0xDEFB

//use labeltext3 for servo ltpurple
#define color_SERVOPINK			0xFE18
#define color_SERVOPURPLE		0x83B7

#define RGBto565(r,g,b) ((((r) & 0xF8) << 8) | (((g) & 0xFC) << 3) | ((b) >> 3))

Adafruit_NeoPixel ledPwrStrip(NEOPIXEL_LED_COUNT, NEOPIXEL_CHAIN_DATAPIN, NEO_GRB + NEO_KHZ800);
Adafruit_NeoPixel ledBoard(1, NEOPIXEL_BOARD_LED_PIN, NEO_GRB + NEO_KHZ800);

// do not fuck with this. 2.0 IS THE BOARD - this call uses hardware SPI
Adafruit_ST7789 tft = Adafruit_ST7789(TFT_CS, TFT_DC, TFT_RST);
//create sensor objects
Adafruit_APDS9960 oColorSensor;
Adafruit_BMP280 oTempBarom;
Adafruit_SHT31 oHumid;

//TFT backlight pin brightness, 0-255
int mnScreenBrightness = 64;
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

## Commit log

2020-02-26 Create Arduino-ConvertedFonts
2020-06-30 Add files via upload
    this version is meant for Adafruit Feather nRF52840 Sense board.
    https://www.adafruit.com/product/4516
2020-09-08 Add files via upload
    added ID and EMRG lights for flip door, as additional neopixels chained to main body power light. ID LED is neopixel address 1, EMRG is address 2. EMRG pulses red.
    [tricorder_sense.ino]
2020-09-11 Add files via upload
    these are early approximations for face button label text, pulled from fontgeek.com
2021-08-04 Update tricorder_sense.ino
    modified white led color to limit pinkish hue
2021-08-10 Add files via upload
    animation, triggering for tom servo screen
2021-08-12 Add files via upload
    fix for kicking out immediately after activation of tom servo screen
    [tricorder_sense.ino]
2021-09-21 Add files via upload
    added support for 6 neopixels on main chain from PWR. if only 3 connected, must set config #define at top of script to 3
2021-10-08 Update tricorder_sense.ino
    bug where stacking behavior not switched back to standard cycling for left side scanner leds
    [tricorder_sense.ino]
2021-11-01 Add files via upload
    added debug flag to enable/disable magnet value testing. added compiler flag to switch between TNG DS9 VOY lcars color layouts. moved magnet sleep threshold to global variable
2021-11-08 Add files via upload
    threshold for sleep set to -20000, added reversed option for profile scroller
    [tricorder_sense.ino]
2021-11-08 Add files via upload
    hope to unify battery health reporting by using a function instead of inline calculations
2021-11-08 Add files via upload
    geo met bio led colors as orange - yellow was not distinct enough from green
2021-11-08 Add files via upload
    changed button orange to same RGB as battery color scale
2021-11-09 Add files via upload
    corrected magnet threshold calculation
    [tricorder_sense.ino]
2021-11-16 Update tricorder_sense.ino
    changed thermal camera throttle to 20FPS / 50ms per frame since it's already throttled by i2c bus speed limit of board.
2021-12-03 Update tricorder_sense.ino
    inverted left/right axis of screen output for thermal camera
    [tricorder_sense.ino]
2022-04-07 Update tricorder_sense.ino
    battery percentage refactor and update to use new reference voltage of 3.6.
    refactor of sleep mode to clear ALL neopixels.
    to-do: debug magnetometer threshold for sleep mode and adjust thermal camera display if hardware rotated 90 deg
2022-04-07 Update tricorder_sense.ino
    added parameter to support thermal camera oriented in portrait mode. tentatively, sketch supports hardware in portrait mode by cropping 32x24 into 24x24 square viewport on screen.
2022-04-08 Update tricorder_sense.ino
    modified magnetometer to use y axis instead of z for sleep mode, as newest version of an adafruit library returning -32768 no matter what.
    if hardware orientation of thermal camera is portrait mode, clip viewport to square on that screen.
    battery % now showing higher accuracy with adafruit change to use 3.6 for reference voltage. as a result, added case to display blue if battery is at 100%
2022-04-10 Update tricorder_sense.ino
    fixed bug when sleep mode triggered while microphone spectrum screen active. battery level calculation fixed to not use decimals in map function call
    [tricorder_sense.ino]
2022-04-11 Update tricorder_sense.ino
    added neopixel color check for sleep mode. if index 1 neopixel is not off, set entire chain as off.
    modified maximum decibel reading to NOT populate until at least 1 legit cycle has been completed.
2022-04-11 Update tricorder_sense.ino
    compile error for mic function fixed
    [tricorder_sense.ino]
2022-06-15 Add files via upload
    removed unneeded reference to arduinojson.h
2022-06-15 Add files via upload
    NOT_AN_INTERRUPT error still gets thrown in compiler for arduino v1.6
2023-05-12 Update rp2040_dvi.ino
    complete refactor to remove all sensor screens, kept neopixel board light logic and board button definition
2023-08-23 Update tricorder_sense.ino
    cleaned up a lot of warning messages. added workaround for dead thermal camera pixel and fixed bug causing temps mapped to array value over 255 to not get truncated to zero
    [tricorder_sense.ino]
2024-06-26 Update tricorder_sense2.ino
    mitigate startup voltage drop, set backlight to 25% for screen
2025-06-16 Add files via upload
    added flag to toggle style of sound trigger.
    false -> sound pin is held low during the entire time sound should be playing.
    true -> sound pin is toggled low briefly to activate playback, then toggled again to end playback.
    version # set to 0.97
2025-08-06 Update PickAndPlace_ButtonPCBv3_CPL.csv
    cleaned up csv format to actually use commas to separate values
    [PickAndPlace_ButtonPCBv3_CPL.csv]
